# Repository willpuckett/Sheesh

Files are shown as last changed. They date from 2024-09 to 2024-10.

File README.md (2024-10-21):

# 🍁 Sheesh

> _Sheesh_ is a tiny board to celebrate the coming of 🍂 with minimal finger
> travel.

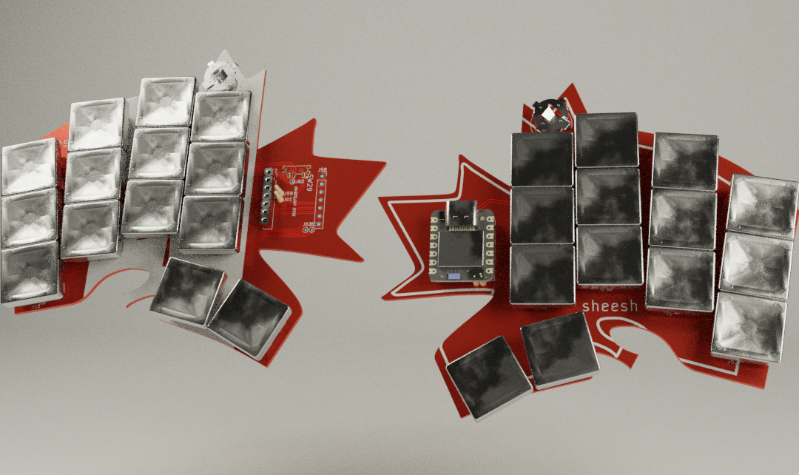
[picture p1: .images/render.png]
Sheesh


After spending the day at my computer, I stepped out with friends Saturday night
for a burger & beverage. On the patio of our local institution, the air was
cool.

> _Autumn had undeniably arrived._

I had been wanting to squeeze a Ferris Sweep out of a Xiao somehow and it
occurred to me as I later continued working that maybe I was actually trying to
make a 28 key keyboard. When I started searching for a board outline, I reached
for a leaf to lay over the keys. I choose a maple leaf both for the aesthetic
quality with which the keys fit, and for the pleasant memories of eating maple
butter in Montreal's Jean-Talon Market it conjured.

> [!NOTE] 
> _Sheesh_ honors the Ojibway people, who (according to the interwebs)
> call maple _sheesheegummavvis_: “sap flows fast."

The size of the Xiao makes it so attractive for smaller keyboards. _Sheesh_
intended to repurpose the reset and nfc pins to squeeze enough I/O to directly
connect the 28 keys. Unfortunately, coopting the reset pin didn't work well,
although the initial exploration revealed a lot more chording opportunities. It
seems to make more sense to explore a 26 key layout in another board, so version
0.2 and up switch to a diode layout. _Sheesh_ is an exploration in PCBA, and
uses 0402 diodes which are not conducive to handsoldering.

> [!IMPORTANT]
> If you have time, please drop a note to your local Seeed representative asking
> that they via the PDM pins (pins 0.16, 1.0, and 1.10) to pads on the underside
> of Xiao nRF52840. [[Seeed USA](mailto:seeed_us@seeed.cc)]
> [[Seeed Europe](mailto:seeed_emea@seeed.cc)]

## BOM

| QTY | Part | JLCPCB Part # |
| :---: | :---: | :---: |
| 2 | BAT-SMD_MY-LR44-02 | C2902345 |
| 2 | SSSS811101 | C109335 |
| 4 | MF254V-11-07-0743 | C2889988 |
| 8 | YZ00615050R-04 | C5157400 |
| 56 (optional) |  3305-0-15-80-47-27-10-0 | C17370797 |
| 28 | ChocV1 switches (Red Pros) | N/A |
| 2 |  3.7V LIR1254 (NOT LR44!)  | N/A |

## Putting it Together



### Fabrication & Assembly Files [[zip](https://github.com/willpuckett/Sheesh/releases/latest/download/jlcpcb.zip)]

For the love of god and country 🇨🇦, please have this fabricated with red mask
and white silk.

> [!CAUTION]
> Use 3.7v LIR1254 (lithium ion rechargable) battery **only**.

## Case



### There's a case [[step](https://github.com/willpuckett/Sheesh/releases/latest/download/case.step)] [[stl](https://github.com/willpuckett/Sheesh/releases/latest/download/case.step)]

It's really more of a skin. Print and place the pcb directly in it. Red or white
TPU is ideal... The case is only one half, flip it in your slicer for the other
half 🙃

> [!TIP]
> Polymaker TPU works well. It seems to like to print slow and cool—leave the
> door open.

TPU is relatively non-slip, absorbing and distributing the force of typing very
nicely. No bumpons required.

## Layouts




Download the latest ZMK Builds.

### Engrammer  [[left](https://github.com/willpuckett/Sheesh/releases/latest/download/sheesh_engrammer_left.uf2)] [[right](https://github.com/willpuckett/Sheesh/releases/latest/download/sheesh_engrammer_right.uf2)] 

Engrammer

## Pre Fabs

The extras will be [available](https://octule.com) when they arrive if you don't
want to have to deal with a minimum order...

## Writing Your Own Keymap

Should you not be prepared for engrammer, you can easily make your own keymap
that references the sheesh shield...

> [!TIP]
> Don't feel like going through the below steps? Unpack
> [this zip](https://github.com/willpuckett/sheesh/config/zmk-config.zip), edit,
> and push to your github account to build.

1. Init a new ZMK repo `bash -c "$(curl -fsSL https://zmk.dev/setup.sh)"`
2. Type `1` to select a keyboard
3. Type `22` to select Seeeduino XIAO BLE
4. Type `Y` to copy in a stock keymap
5. Ender your github username so you can push your config to build it
6. Type `Y` to execute it
7. You can delete the `boards` and `zephyr` directories to keep things tidy
8. In `build.yaml`, change the `shield` to `sheesh`
9. In the config directory, rename the `.conf` and `.keymap` files to `sheesh`,
   keeping their respective `.conf` and `.keymap` extensions it should look like
   this:

```bash
❯ ls --tree zmk-config/config
config
├── sheesh.conf
├── sheesh.keymap
└── west.yml
```

10. In the same directory, edit `west.yml` to look like this:

```yaml
manifest:
  remotes:
    - name: zmkfirmware
      url-base: https://github.com/zmkfirmware
    # Additional modules containing boards/shields/custom code can be listed here as well
    # See https://docs.zephyrproject.org/3.2.0/develop/west/manifest.html#projects
    - name: willpuckett
      url-base: https://github.com/willpuckett
  projects:
    - name: zmk
      remote: zmkfirmware
      revision: main
      import: app/west.yml
    - name: sheesh
      remote: willpuckett
      repo-path: sheesh/config
      revision: main
  self:
    path: config
```

11. Edit `config/sheesh.keymap`. You can start by copying in one of the
    [layers from this file](https://github.com/willpuckett/sheesh/config/boards/shields/sheesh/sheesh.keymap)
    as a starting point. Then push the folder to your github to build in an
    action.

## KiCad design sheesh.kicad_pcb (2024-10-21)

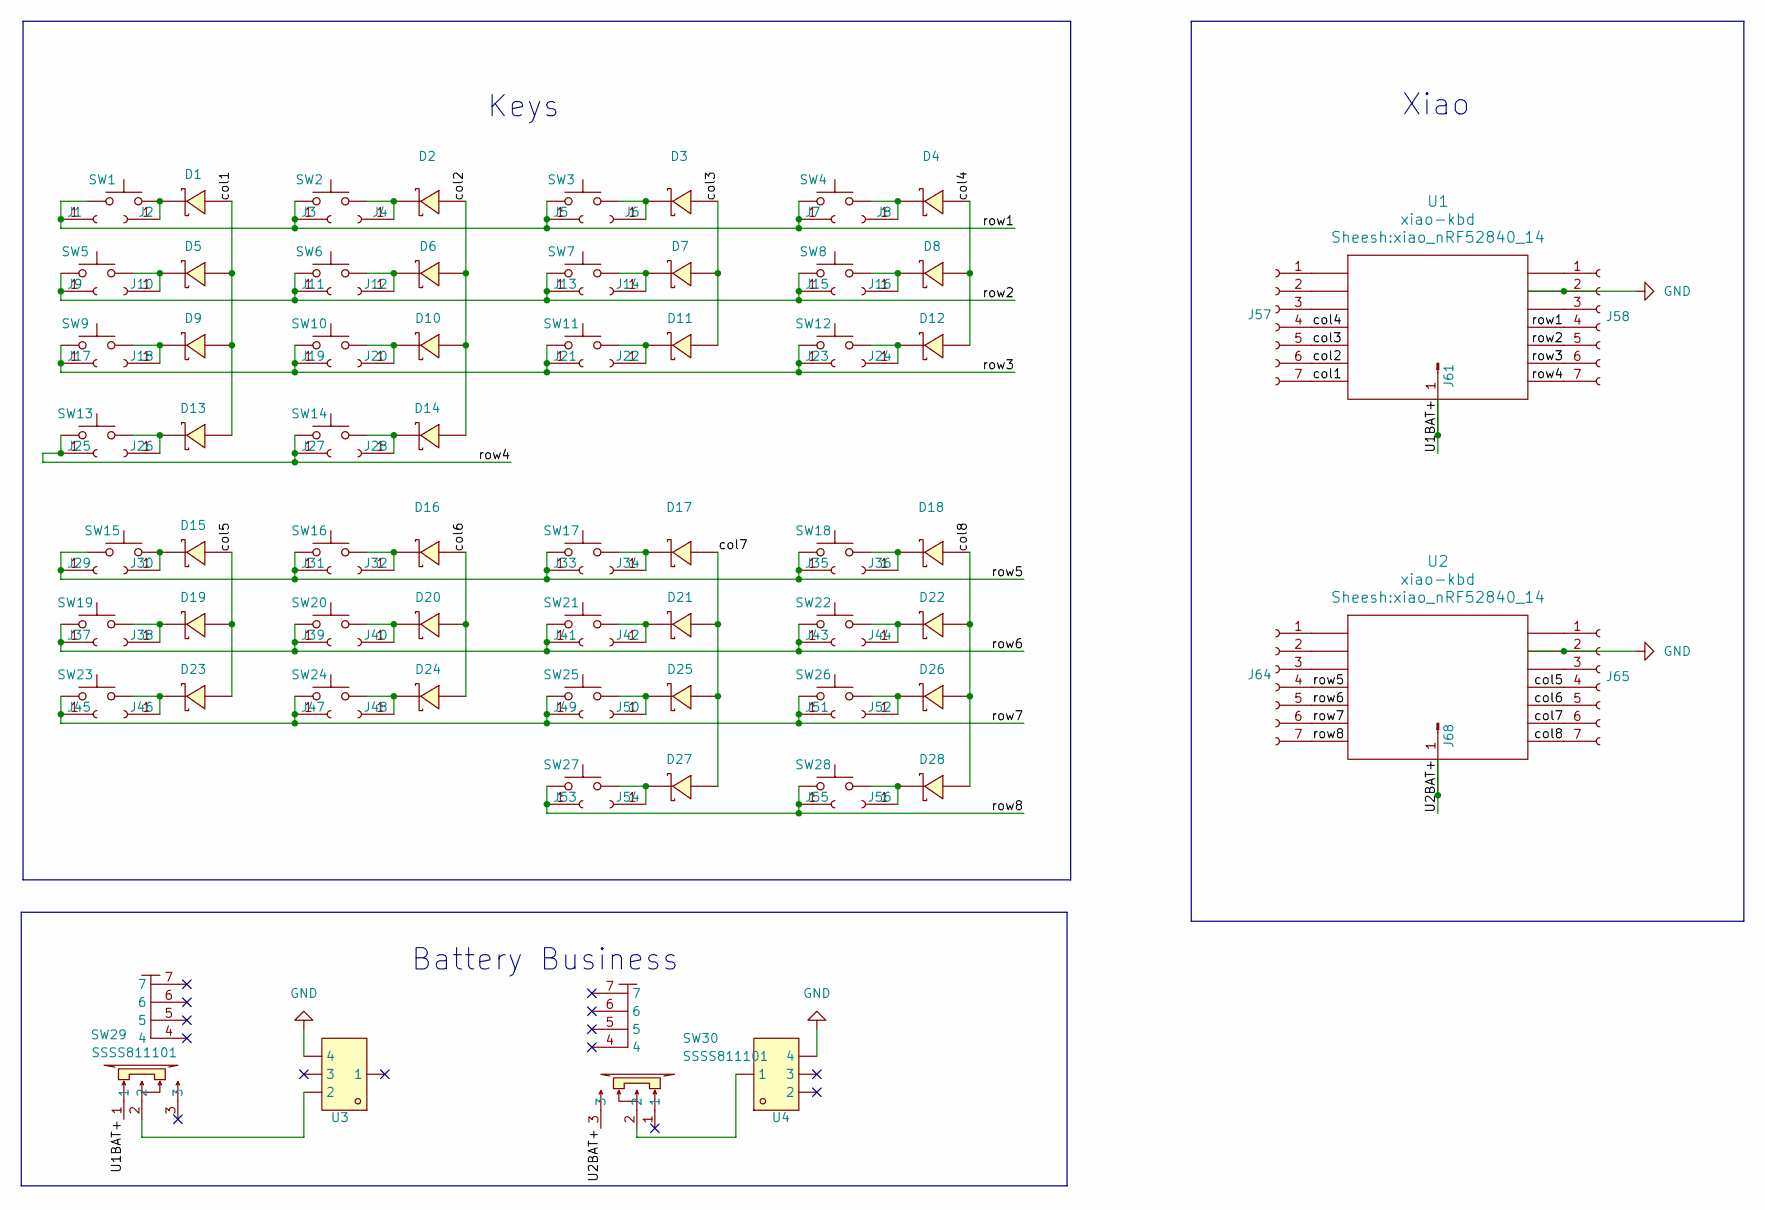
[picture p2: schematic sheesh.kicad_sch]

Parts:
D1, D2, D3, D4, D5, D6, D7, D8, D9, D10, D11, D12, D13, D14, D15, D16, D17, D18, D19, D20, D21, D22, D23, D24, D25, D26, D27, D28: CDSQC4148-HF; X1-DFN1006-2_L1.0-W0.6-RD; LCSC C6341459
J1, J2, J3, J4, J5, J6, J7, J8, J9, J10, J11, J12, J13, J14, J15, J16, J17, J18, J19, J20, J21, J22, J23, J24, J25, J26, J27, J28, J29, J30, J31, J32, J33, J34, J35, J36, J37, J38, J39, J40, J41, J42, J43, J44, J45, J46, J47, J48, J49, J50, J51, J52, J53, J54, J55, J56: 3305-0-15-80-47-27-10-0; MPN 3305-0-15-80-47-27-10-0; LCSC C17370797
J57, J58, J64, J65: MF254V-11-07-0743; MPN 310-13-107-41-001000; LCSC C2889988
J61, J68: YZ00615050R-04; MPN 0906-2-15-20-75-14-11-0; LCSC C5157400
SW1, SW2, SW3, SW4, SW5, SW6, SW7, SW8, SW9, SW10, SW11, SW12, SW13, SW14, SW15, SW16, SW17, SW18, SW19, SW20, SW21, SW22, SW23, SW24, SW25, SW26, SW27, SW28: SW_Push; SW_PG1350
SW29, SW30: SSSS811101; SW-SMD_SSSS811101; LCSC C109335
U1, U2: xiao-kbd; xiao_nRF52840_14
U3, U4: MY-LR44-02; BAT-SMD_MY-LR44-02; MPN MY-LR44-02; LCSC C2902345

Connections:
/U1BAT+: J61.1, SW29.1, U1.17 (BAT+)
/U2BAT+: J68.1, SW30.3, U2.17 (BAT+)
/col1: D1.2 (A), D5.2 (A), D9.2 (A), D13.2 (A), J57.7, U1.7 (D6)
/col2: D2.2 (A), D6.2 (A), D10.2 (A), D14.2 (A), J57.6, U1.6 (D5)
/col3: D3.2 (A), D7.2 (A), D11.2 (A), J57.5, U1.5 (D4)
/col4: D4.2 (A), D8.2 (A), D12.2 (A), J57.4, U1.4 (D3)
/col5: D15.2 (A), D19.2 (A), D23.2 (A), J65.4, U2.11 (D10)
/col6: D16.2 (A), D20.2 (A), D24.2 (A), J65.5, U2.10 (D9)
/col7: D17.2 (A), D21.2 (A), D25.2 (A), D27.2 (A), J65.6, U2.9 (D8)
/col8: D18.2 (A), D22.2 (A), D26.2 (A), D28.2 (A), J65.7, U2.8 (D7)
/row1: J1.1, J3.1, J5.1, J7.1, J58.4, SW1.1, SW2.1, SW3.1, SW4.1, U1.11 (D10)
/row2: J9.1, J11.1, J13.1, J15.1, J58.5, SW5.1, SW6.1, SW7.1, SW8.1, U1.10 (D9)
/row3: J17.1, J19.1, J21.1, J23.1, J58.6, SW9.1, SW10.1, SW11.1, SW12.1, U1.9 (D8)
/row4: J25.1, J27.1, J58.7, SW13.1, SW14.1, U1.8 (D7)
/row5: J29.1, J31.1, J33.1, J35.1, J64.4, SW15.1, SW16.1, SW17.1, SW18.1, U2.4 (D3)
/row6: J37.1, J39.1, J41.1, J43.1, J64.5, SW19.1, SW20.1, SW21.1, SW22.1, U2.5 (D4)
/row7: J45.1, J47.1, J49.1, J51.1, J64.6, SW23.1, SW24.1, SW25.1, SW26.1, U2.6 (D5)
/row8: J53.1, J55.1, J64.7, SW27.1, SW28.1, U2.7 (D6)
GND: J58.2, J65.2, U1.13 (GND), U2.13 (GND), U3.4, U4.4
unnamed: D1.1 (K), J2.1, SW1.2
unnamed: D2.1 (K), J4.1, SW2.2
unnamed: D3.1 (K), J6.1, SW3.2
unnamed: D4.1 (K), J8.1, SW4.2
unnamed: D5.1 (K), J10.1, SW5.2
unnamed: D6.1 (K), J12.1, SW6.2
unnamed: D7.1 (K), J14.1, SW7.2
unnamed: D8.1 (K), J16.1, SW8.2
unnamed: D9.1 (K), J18.1, SW9.2
unnamed: D10.1 (K), J20.1, SW10.2
unnamed: D11.1 (K), J22.1, SW11.2
unnamed: D12.1 (K), J24.1, SW12.2
unnamed: D13.1 (K), J26.1, SW13.2
unnamed: D14.1 (K), J28.1, SW14.2
unnamed: D15.1 (K), J30.1, SW15.2
unnamed: D16.1 (K), J32.1, SW16.2
unnamed: D17.1 (K), J34.1, SW17.2
unnamed: D18.1 (K), J36.1, SW18.2
unnamed: D19.1 (K), J38.1, SW19.2
unnamed: D20.1 (K), J40.1, SW20.2
unnamed: D21.1 (K), J42.1, SW21.2
unnamed: D22.1 (K), J44.1, SW22.2
unnamed: D23.1 (K), J46.1, SW23.2
unnamed: D24.1 (K), J48.1, SW24.2
unnamed: D25.1 (K), J50.1, SW25.2
unnamed: D26.1 (K), J52.1, SW26.2
unnamed: D27.1 (K), J54.1, SW27.2
unnamed: D28.1 (K), J56.1, SW28.2
unnamed: J57.1, U1.1 (D0)
unnamed: J57.2, U1.2 (D1)
unnamed: J57.3, U1.3 (D2)
unnamed: J58.1, U1.14 (5v)
unnamed: J58.3, U1.12 (3v3)
unnamed: J64.1, U2.1 (D0)
unnamed: J64.2, U2.2 (D1)
unnamed: J64.3, U2.3 (D2)
unnamed: J65.1, U2.14 (5v)
unnamed: J65.3, U2.12 (3v3)
unnamed: SW29.2, U3.2
unnamed: SW30.2, U4.1

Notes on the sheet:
Battery Business
Keys
Xiao

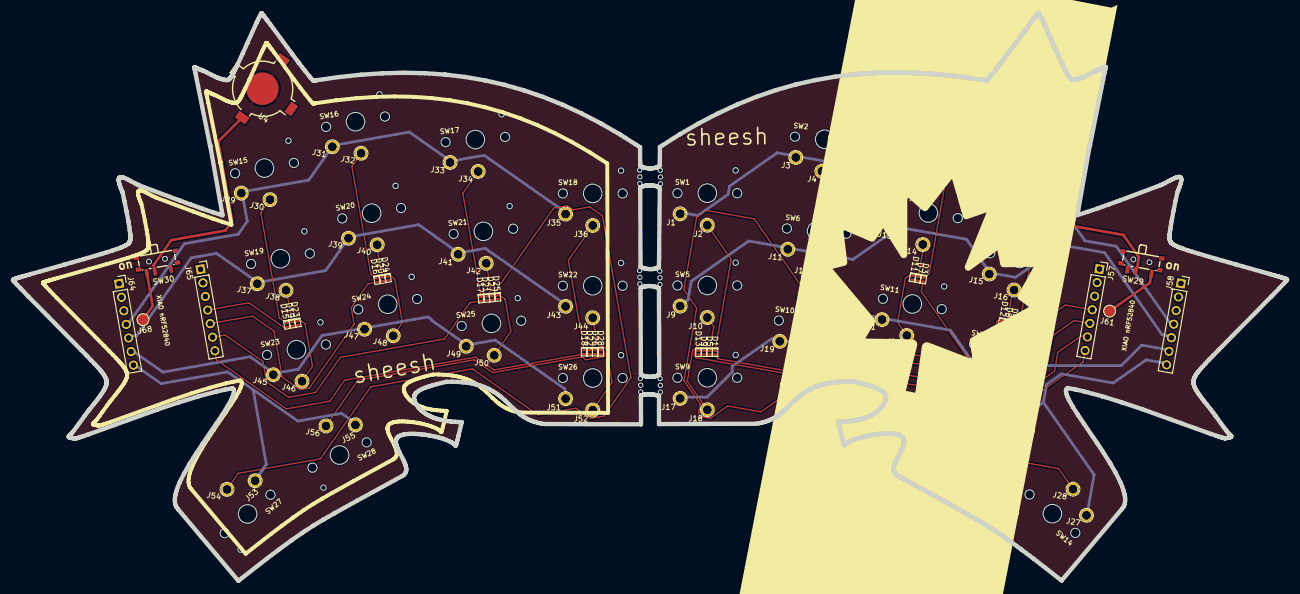
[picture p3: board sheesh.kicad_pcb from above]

Board: 2 copper layers, 234.7 x 104.6 mm, 124 parts (0 on the bottom side), 59 nets.

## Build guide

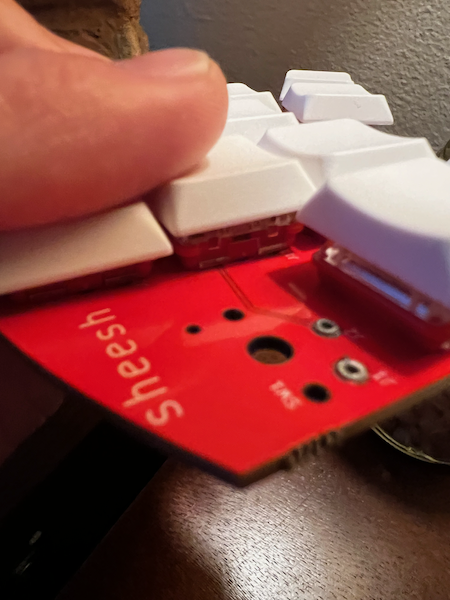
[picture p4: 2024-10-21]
.images/3305-installation.png

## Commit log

2024-09-26 ignore erc error
    [sheesh.kicad_pcb]
2024-09-27 fix(sw-th_ssss811101): swap SW29 & SW30 symbol & footprint
    Change PCM12SMTR to SSSS811101. The latter fits on the former's footprint, but the location was
    slightly off fin the cpl
    [sheesh.kicad_pcb, sheesh.kicad_sch]
2024-09-27 fix(component): correct lcsc field name on ssss811101
    correct lcsc field name so it passes kibot filter
    [sheesh.kicad_pcb, sheesh.kicad_sch]
2024-09-27 style(component): nudge switch away from pogo pin
    nudge power switch for more comfortable clearance
    [sheesh.kicad_pcb]
2024-09-27 fix(pcb): add space between potential shorts
    slightly adjust further recently updated switches and pogo pins to reduce the chance of failure
    [sheesh.kicad_pcb]
2024-10-03 fix(sheesh.keymap): change directive
    switch to elif from elseif
2024-10-14 try setting reset pin in conf option, correct pin numbers on right half
2024-10-21 switch to diodes
    [sheesh.kicad_pcb, sheesh.kicad_sch]
2024-10-21 clean up switch to diodes
    [sheesh.kicad_pcb]
2024-10-21 refill zones
    [sheesh.kicad_pcb]
2024-10-21 remove switch back silk
    [sheesh.kicad_pcb]
2024-10-21 correct diode text and part number
    [sheesh.kicad_pcb, sheesh.kicad_sch]
2024-10-21 remove deprecated silks
    [sheesh.kicad_pcb]
2024-10-21 remove mousebites from position file
    [sheesh.kicad_pcb]
2024-10-21 remove deprecated silk
    [sheesh.kicad_pcb]
